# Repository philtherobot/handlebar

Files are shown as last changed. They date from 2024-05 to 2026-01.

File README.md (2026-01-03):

### Ergogen

Online design tool at https://ergogen.cache.works/.

Elite-C https://deskthority.net/wiki/Elite-C footprint from ceoloide: https://github.com/ceoloide/ergogen-footprints

Running ergogen:

```
cd handlebar
ergogen . -o output
```

Pass a folder instead of an input file name because handlebar has custom footprints and that's how this works.

### Parts

- Choc v1 switches (Keebd)
- DMK keycaps, 1U (Keebd)
- Elite-C v4, 2 parts (Omega Keys)
- TRRS PJ-320A jack, 2 parts (Clickety Split)
- TRRS cable (Clickety Split)
- Diodes 1N4148W, SOD-123, 50 parts (Digikey 4530-1N4148WCT-ND)
- Push buttons FSMCTTR, 2 parts (Digikey 450-2133-1-ND)
- RGB LEDs FZ2812-5050, QMK compatible (WS2812B) (Digikey, 4544-FZ2812-5050CT-ND)
- MCU socket 801-43-064-10-002000 (Digikey, ED10864-64-ND)
- PCBs, 2 parts
- USB-C/USB cable

The Atmega32u4 on the Elite-C has 32KB flash, 2.5KB SRAM, 16MHz CPU.

#### Base

Mild steel plate, 1/16", 5/64" or 3/32" thick. 1.5mm to 2.5mm thick. 200x150mm or 8"x6", two times.

We plan to either solder the standoff or screw them.

- 8mm long, M2 standoff, 6 times
- dome head M2 screws, 6mm of thread, 6 times
- dome head M2 screws, 4mm of thread, 8 times
- flat head M2 screws, 6mm full length, 6 times
- flat head M2 screws, 10mm full length, 8 times
- M2 nuts, 8 times

### Cost

Elite-C at Omega Keys, 24$ each.
Keycaps and switches, 114$
PCB, JLCPcb, 
TRRS cable
Digi-key

#### Not used, extra
Switches, 13$
TRRS cable, Keebd, 7$ (not used)

### KiCAD 

Tutorial: https://flatfootfox.com/ergogen-part5-kicad-firmware-assembly/

We are better to use constraints from makers. JLCPCB seems to have less capability than others. I found a Kicad board with JLC's capability set. See `JLCPCB_1-2Layer template`.

*DO NOT* edit the elite-c footprint as this will introduce a lot of errors! The errors are introduced because the nets that were setup by Ergogen are lost during the footprint edition.

Steps after ergogen has been executed:
- Import board settings from JLCPCB_1-2Layer template:
  - File/Board Setup/Import from another board. 
  - Turn User.Drawings back on.
  - Change track width to 0.25mm in Net Classes
- add the resistors footprints, R_Axial_DIN0207_L6.3mm_D2.5mm_P10.16mm_Horizontal
  - under the TRRS
  - do not show the reference
- change footprint of indicators to Personal:WS2812B
- (useful: Route/Interactive Router Setting, try Highlight + Free angle or Walk around)
- complete the net connections for the resistors on front of board (VCC on the right, SDA at the top, SCL at the bottom)
- add a via below the indicators for VCC
- wire keys pin 1 (2 of them) to diode 2 on the back
- wire diode pads to holes on the front and back
- wire columns on the back
- route columns around the top and through the middle of the MCU, starting with n_inner
- wire rows on the front: they enter the MCU from the left
- wire reset, place it on the right
- wire VCC on the left of reset *and* go from the second resistor to the via on the *back*
- wire ground, going between n_vcc and n_scl on the TRRS connector, up on the left of VCC
- wire ground to all ground pins on the MCU
- wire SDA from TRRS to the MCU on the back
- indicator grounds
- indicator "next" and to the MCU

Optional:
- give a little bit of space around pads and traces
- add the name and version on the silkscreens

### Fabrication

Prepare Gerber files:
- File/Fabrication/Gerbers
- Check the layers
  - *.Cu, *.Paste, *.Mask, *.Silkscreen, Edge.Cuts
- Set a clean, new, empty directory
- Plot
- Generate drill files
- Zip the output files, flat, no directory

Upload to JLCPCB (https://jlcpcb.com/)

PCB material is FR-4. Use the defaults (1.6mm). Remove JLC's serial numper. Pick your color. 

### Notes

Elite-C information:
- https://deskthority.net/wiki/Elite-C
- Development history, reveals a lot about how it works: https://blog.keeb.io/case-of-the-wayward-elite-c/
- Atmega34U4, Atme AVR

https://flatfootfox.com/ergogen-part3-pcbs/

This has example of adding a PCB via: https://github.com/ergogen/ergogen/blob/675d2709dc4c2515ec34ecf4e5148127495283f3/config.yaml

PCM12 is a sliding switch. (no need it seems)

b3u1000p is a small reset push button. https://www.allaboutcircuits.com/electronic-components/datasheet/B3U-1000P-B--Omron/

This looks close to what I am trying to do: https://github.com/davidphilipbarr/Sweep/tree/main/Sweep%20half-swept

Redox schematic https://github.com/mattdibi/redox-keyboard/blob/master/redox/pcb/Redox-schematic.pdf

# Hardware Checklist

- [x] MCU position on the PCB matches the one in the preview.
- [x] Through holes are the correct size for my components.
- [x] Fit between the diode and the switch.
- [x] Pull up 4.7KΩ resistors, SDA to VCC, SCL to VCC
- [x] Must I²C be connected to those two specific pins? D0 and D1? Yes, let's do that.
- [x] Should I ground all unused pins? No. And there is no need to cover the unused space with ground copper.
- [x] Are the back diodes pads connected to the traces on front? No and I added them.
- [x] Decide on PCB thickness: 1.6mm
- [x] What is the voltage needed by the RGB LEDs? 3V, so VCC is good. Crossed fingers.

# Key Layout

Diagrams are made with [Keyboard Layout Editor](https://www.keyboard-layout-editor.com/).

I have linked the Keyboard Layout Editor account with my Github account. In any case, I saved the diagrams to `key_layout`.

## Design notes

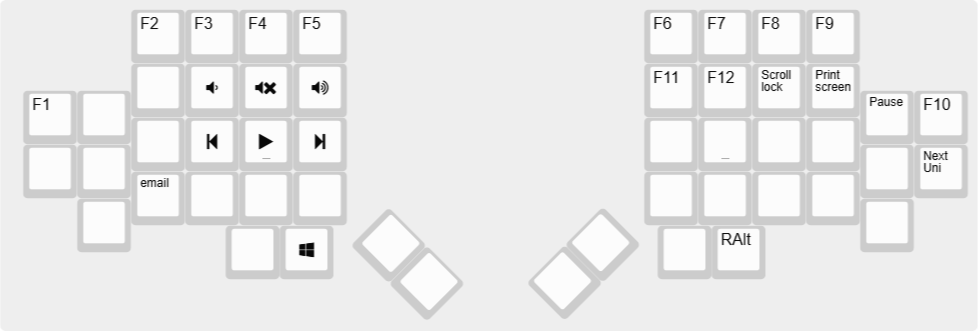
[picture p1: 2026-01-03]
key_layout/jan2026/handlebar-functions.png

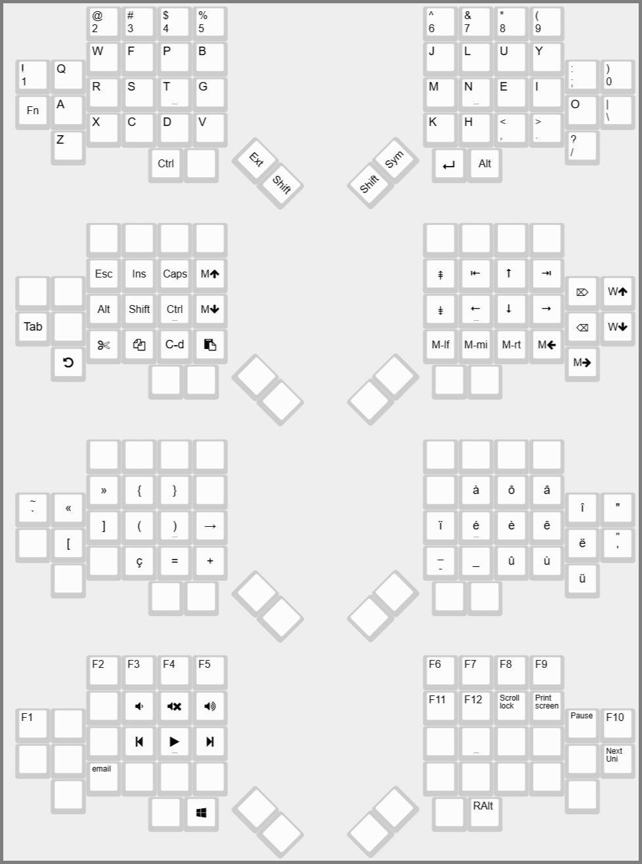
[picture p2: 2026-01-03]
key_layout/jan2026/handlebar-layout.png

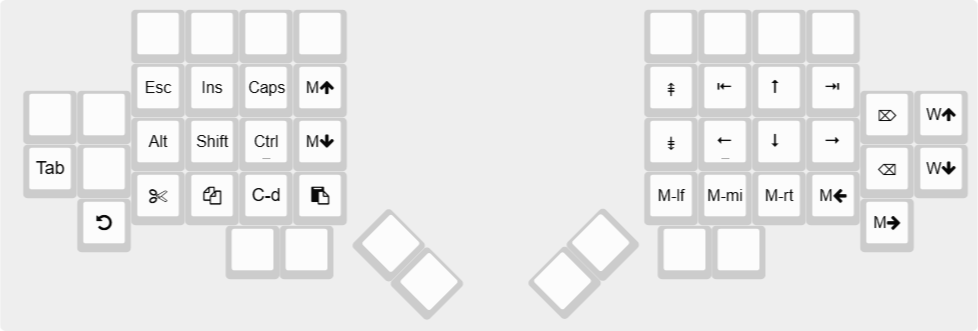
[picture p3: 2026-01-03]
key_layout/jan2026/handlebar-extend.png

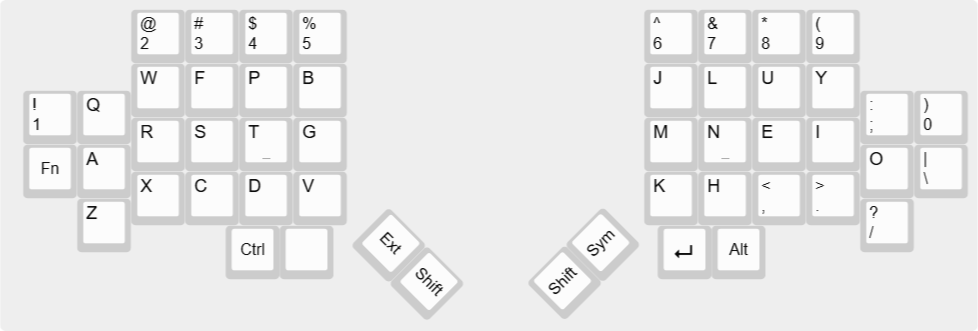
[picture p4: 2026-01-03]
key_layout/jan2026/handlebar-base-layer.png

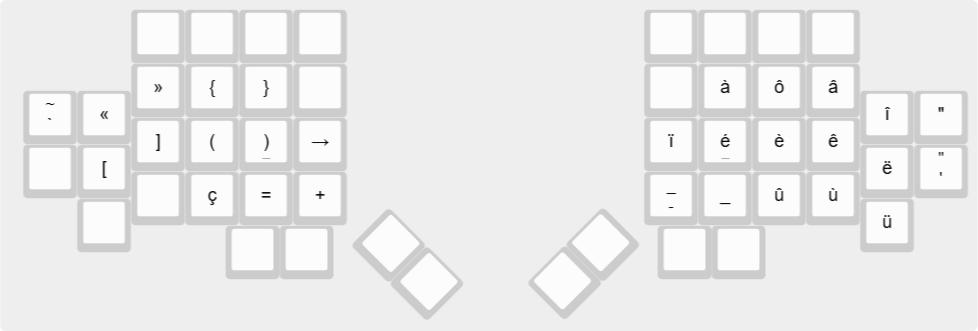
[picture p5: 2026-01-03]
key_layout/jan2026/handlebar-symbols.png

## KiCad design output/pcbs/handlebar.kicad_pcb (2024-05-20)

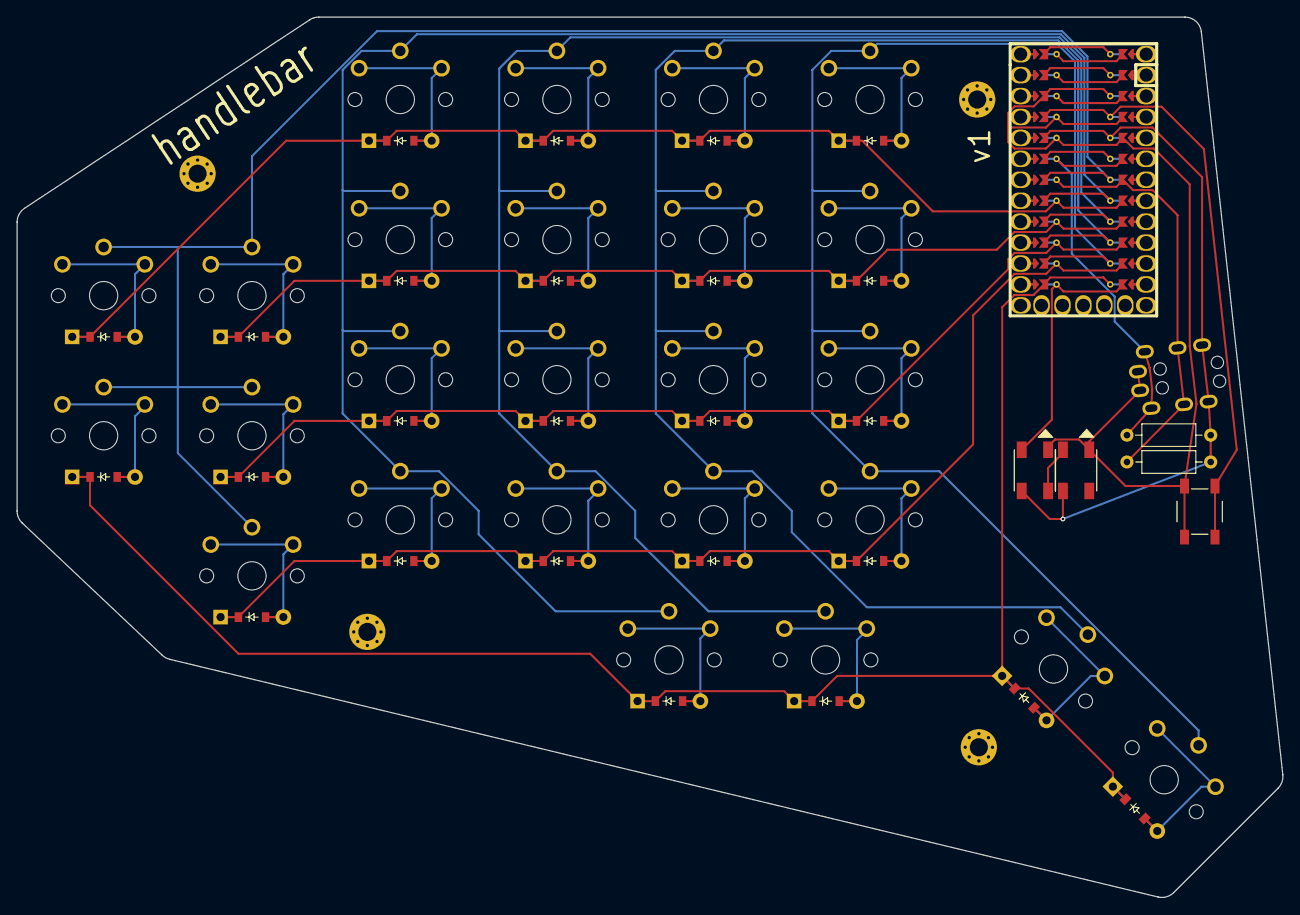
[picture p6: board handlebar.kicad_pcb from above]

Board: 4 copper layers, 153.6 x 106.8 mm, 58 parts (0 on the bottom side), 38 nets.

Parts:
D1, D2, D3, D4, D5, D6, D7, D8, D9, D10, D11, D12, D13, D14, D15, D16, D17, D18, D19, D20, D21, D22, D23, D24, D25: ComboDiode
I1, I2: WS2812B
S1, S2, S3, S4, S5, S6, S7, S8, S9, S10, S11, S12, S13, S14, S15, S16, S17, S18, S19, S20, S21, S22, S23, S24, S25: PG1350
TRRS1: TRRS-PJ-320A-dual
_2, _3, _4, _5: MountingHole_2.2mm_M2_Pad_Via
rst1: SW_TACT_ALPS_SKQGABE010

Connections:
center_thumb: D24.2, S24.1
index_bottom: D9.2, S9.1
index_home: D10.2, S10.1
index_nums: D12.2, S12.1
index_top: D11.2, S11.1
inner_bottom: D13.2, S13.1
inner_home: D14.2, S14.1
inner_nums: D16.2, S16.1
inner_thumb: D25.2, S25.1
inner_top: D15.2, S15.1
left_thumb: D22.2, S22.1
middle_bottom: D5.2, S5.1
middle_home: D6.2, S6.1
middle_nums: D8.2, S8.1
middle_top: D7.2, S7.1
n_bottom: D1.1, D5.1, D9.1, D13.1, D19.1
n_gnd: I1.33, I2.33, TRRS1.1, rst1.2
n_home: D2.1, D6.1, D10.1, D14.1, D20.1
n_index: S9.2, S10.2, S11.2, S12.2, S24.2
n_indic_next: I1.22, I2.44
n_inner: S13.2, S14.2, S15.2, S16.2, S25.2
n_middle: S5.2, S6.2, S7.2, S8.2, S23.2
n_nums: D4.1, D8.1, D12.1, D16.1, D18.1
n_pinky: S17.2, S18.2, S19.2, S20.2, S21.2
n_ring: S1.2, S2.2, S3.2, S4.2, S22.2
n_thumb: D17.1, D22.1, D23.1, D24.1, D25.1
n_top: D3.1, D7.1, D11.1, D15.1, D21.1
n_vcc: I1.11, I2.11, TRRS1.4
outer_home: D17.2, S17.1
outer_top: D18.2, S18.1
pinky_bottom: D19.2, S19.1
pinky_home: D20.2, S20.1
pinky_top: D21.2, S21.1
right_thumb: D23.2, S23.1
ring_bottom: D1.2, S1.1
ring_home: D2.2, S2.1
ring_nums: D4.2, S4.1
ring_top: D3.2, S3.1

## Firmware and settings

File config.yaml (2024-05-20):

meta:
  version: 1
  author: philtherobot
  engine: 4.0.2
units:
  # cx, cy = Choc V1 spacing, 18×17
  # physical DMK keycap size = 17.5×16.5
  # We want a familiar horizontal spacing.
  # So spread = 19 (standard = u).
  # We want tighter as possible vertically
  # because we have four rows.
  # So padding = 17 (cy)

  spread: u     # 19mm
  padding: cy   # 17mm
  kcapx: 17.5
  kcapy: 16.5

  # Shifts around points to stretch the "board" polygon
  bpadx: cx / 2 + 1.5 
  bpady: cy / 2 + 1.5

  mcuwidth: 17.78
  mcuheight: 33.02
  mcushiftx: 0.5cx + mcuwidth/2 + 8
  mcushifty: 0.5cy - mcuheight/2 - 3

  resetwidth: 5
  resetheight: 5
  resetshiftx: 40
  resetshifty: -50

  trrswidth: 6
  trrsheight: 14
  trrsshiftx: 44
  trrsshifty: -34
  trrsrotate: -83.4

  indicatorwidth: 5
  indicatorheight: 5
  indicatorshiftx: 20
  indicatorshifty: -45

points:
  key:
    spread: spread
    padding: padding

  zones:
    # The central 4×4 matrix
    center:
      # Fix placement on KiCAD sheet.
      anchor:
        shift: [100, -100]

      columns:
        ring:
          key:
            col_net: n_ring
        middle:
          key:
            col_net: n_middle
        index:
          key:
            col_net: n_index
        inner:
          key:
            col_net: n_inner

      rows:
        bottom:
          row_net: n_bottom
        home:
          row_net: n_home
        top:
          row_net: n_top
        nums:
          row_net: n_nums

    # The keys at the outer edge
    wing:
      key:
        spread: cx  # Tighter spread for the pinky
        col_net: n_pinky # All those keys are in a single net column

      anchor:
        ref: center_ring_bottom
        shift: [-2cx, -0.4cy]

      columns:
        outer:
          rows:
            bottom.skip: true
            home.row_net: n_thumb
            top.row_net: n_nums
        pinky:

      rows:
        bottom:
          row_net: n_bottom
        home:
          row_net: n_home
        top:
          row_net: n_top

    # The lower keys for the thumb
    thumb:
      anchor:
        ref: center_index_bottom
        shift: [-0.3cx, -padding]
      columns:
        left:
           key:
             col_net: n_ring
        right:
          key:
            col_net: n_middle
        center:
          key:
            splay: -45
            origin: [3, -11]
            col_net: n_index
        inner:
          key:
            col_net: n_inner
      rows:
        thumb:
          row_net: n_thumb

outlines:
  # "keycaps" is the positions of the DMK keycaps
  keycaps:
    - what: rectangle
      where: true
      size: [kcapx, kcapy]

  raw:
    - what: rectangle
      where: true
      size: [cx+1, cy+1]

  board:
    - what: polygon
      fillet: 2
      points:
        - ref: wing_outer_home
          shift: [-bpadx, -bpady]
        - ref: wing_outer_top
          shift: [-bpadx, bpady]
        - ref: center_ring_nums
          shift: [-bpadx, bpady]
        - ref: center_inner_nums
          shift: [bpadx, bpady]
        - ref: center_inner_nums
          shift: [40, bpady]
        - ref: thumb_inner_thumb
          shift: [bpadx, bpady]
        - ref: thumb_inner_thumb
          shift: [bpadx, -bpady]
        - ref: wing_pinky_bottom
          shift: [-bpadx, -bpady]

  mcu:
    - what: rectangle
      size: [mcuwidth, mcuheight]
      adjust: 
        ref: center_inner_nums
        shift: [mcushiftx, mcushifty] 

  reset:
    - what: rectangle
      size: [resetwidth, resetheight]      
      adjust:
        ref: center_inner_nums
        shift: [resetshiftx, resetshifty]

  trrs:
    - what: rectangle
      size: [trrswidth, trrsheight]
      adjust: 
        ref: center_inner_nums
        shift: [trrsshiftx - 5, trrsshifty - 1]
        rotate: trrsrotate

  indicator1:
    - what: rectangle
      size: [indicatorwidth, indicatorheight]
      adjust:
        ref: center_inner_nums
        shift: [indicatorshiftx, indicatorshifty]

  indicator2:
    - what: rectangle
      size: [indicatorwidth, indicatorheight]
      adjust:
        ref: center_inner_nums
        shift: [indicatorshiftx + indicatorwidth, indicatorshifty]

  preview:
    - name: board
    - operation: stack
      name: keycaps
    - operation: stack
      name: mcu 
    - operation: stack
      name: reset
    - operation: stack
      name: trrs  
    - operation: stack
      name: indicator1
    - operation: stack
      name: indicator2
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

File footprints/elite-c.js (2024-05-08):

/*

Author: @Virginia2244

Description:
  A reversable footprint for the elite-c microcontroller.

Datasheet: (really just a wiki but it was the closest I could find)
  https://deskthority.net/wiki/Elite-C

Params
  reversable: default is false
    When enabled the PCB is reversable
  label: default is true
    Turns on and off the elite-c label
  instructions: default is true
    turns on and off the instructions about which side to solder the
  jumpers traces: default is true
    Turns on and off auto tracing for the reversable pins
  reversable_pins: default is 5
    How many pins need to be reversable? Only the top 5 need to
    be reversable because they aren't GPIO. After that the pins are changable in
    the firmware.
*/


module.exports = {
  params : {
    reversable : {type : 'boolean', value : false},
    label : {type : 'boolean', value : true},
    instructions : {type : 'boolean', value : true},
    traces : {type : 'boolean', value : true},
    reversable_pins : {type : 'boolean', value : 5},

    D3 : {type : 'net', value : 'D3'},
    D2 : {type : 'net', value : 'D2'},
    D1 : {type : 'net', value : 'D1'},
    D0 : {type : 'net', value : 'D0'},
    D4 : {type : 'net', value : 'D4'},
    C6 : {type : 'net', value : 'C6'},
    D7 : {type : 'net', value : 'D7'},
    E6 : {type : 'net', value : 'E6'},
    B4 : {type : 'net', value : 'B4'},
    B5 : {type : 'net', value : 'B5'},

    B0 : {type : 'net', value : 'B0'},
    F4 : {type : 'net', value : 'F4'},
    F5 : {type : 'net', value : 'F5'},
    F6 : {type : 'net', value : 'F6'},
    F7 : {type : 'net', value : 'F7'},
    B1 : {type : 'net', value : 'B1'},
    B3 : {type : 'net', value : 'B3'},
    B2 : {type : 'net', value : 'B2'},
    B6 : {type : 'net', value : 'B6'},

    VBUS : {type : 'net', value : 'VBUS'},
    GND : {type : 'net', value : 'GND'},
    RST : {type : 'net', value : 'RST'},
    VCC : {type : 'net', value : 'VCC'},

    B7 : {type : 'net', value : 'B7'},
    D5 : {type : 'net', value : 'D5'},
    C7 : {type : 'net', value : 'C7'},
    F1 : {type : 'net', value : 'F1'},
    F0 : {type : 'net', value : 'F0'},

  },
  body : p => {
      /* Putting the nets into an array so that it can be itterated through */
      const pin_nets = [
        [`${p.VBUS.str}`, `${p.VBUS.str}`],
        [`${p.D3.str}`,   `${p.B0.str}`],
        [`${p.D2.str}`,   `${p.GND.str}`],
        [`${p.GND.str}`,  `${p.RST.str}`],
        [`${p.GND.str}`,  `${p.VCC.str}`],
        [`${p.D1.str}`,   `${p.F4.str}`],
        [`${p.D0.str}`,   `${p.F5.str}`],
        [`${p.D4.str}`,   `${p.F6.str}`],
        [`${p.C6.str}`,   `${p.F7.str}`],
        [`${p.D7.str}`,   `${p.B1.str}`],
        [`${p.E6.str}`,   `${p.B3.str}`],
        [`${p.B4.str}`,   `${p.B2.str}`],
        [`${p.B5.str}`,   `${p.B6.str}`],
      ]

      /*These constants are the magic of this code, they allow us to adjust almost everything important aspect of the microcontroller.
      The reason this is helpfull is that if you don't want to use a Seeed Xiao you can easily adjust the paramiters to make a different microcontroller.
      
      top_left_pin: This is the position of the top left pin of the microcontroller.
      top_right_pin: This is the position of the top right pin of the microcontroller.
      pin_dist: The distance in between each pin horizontaly
      total_pin_num: The total number of pins the microcontroller has. This number must be divisable by two.
      pin_to_male_pad: The distance from the pin on the microcontroller to the male pad.
      pin_to_female_pad: The distance from the pin on te microcontroller to the female pad.
      pin_to_via: the distance from the pin on the microcontroller to the via.
      */
      const spacing = {
        top_left_pin:  {x: -7.62, y: -16.51},
        top_right_pin: {x:  7.62, y: -16.51}, 
        pin_dist: 2.54,
        total_pin_num: 26, //Must be an even number
        pin_to_male_pad: 2,
        pin_to_female_pad: 2.845,
        pin_to_via: 4.358,
      }

      /*The other distances needed to make the traces work. This is basically just two points. 
      
      top_left      top_right
        ^              ^
        /``````````````\
       [] 0             O []
           \............../
            ^             ^
      bottom_left   bottom_right

      The number is the distance from the pin to the corner of the trace. */
      const trace_spacing = {
        top_left:     {x: 3.6, y: .85},
        top_right:    {x: 5.2, y: .85},
        bottom_left:  {x: 5.2, y: .85},
        bottom_right: {x: 3.6, y: .85},
      }

      /*Generates the through holes on sides of the microcontroller*/
      const get_thru_hole = () => {
        let thru_hole = ''
        /* Starts at the top two microcontrollers and goes down. 
        It makes the nets of each pin internal if it suposed to be a reversable pin otherwise it takes from the pin_nets values.*/
        for (let i = 0; i < spacing.total_pin_num/2; i++) {
          // Only place a pin hole for the top VCC if it reversavle
          if(i == 0){
            thru_hole += p.reversable ? `(pad ${i} thru_hole oval (at ${spacing.top_left_pin.x}  ${spacing.top_left_pin.y + (i)*spacing.pin_dist}  ${p.rot})       (size 2.5 2) (drill 1.6) (layers *.Cu *.Mask) 
            ${pin_nets[i][0]})\n` : ``
          
            thru_hole +=`(pad ${spacing.total_pin_num - 1 - i} thru_hole oval (at ${spacing.top_right_pin.x} ${spacing.top_right_pin.y + (i)*spacing.pin_dist} ${180 + p.rot}) (size 2.5 2) (drill 1.6) (layers *.Cu *.Mask) ${pin_nets[i][1]})\n`
            continue;
          }
          thru_hole += `(pad ${i}                             thru_hole oval (at ${spacing.top_left_pin.x}  ${spacing.top_left_pin.y + (i)*spacing.pin_dist}  ${p.rot})       (size 2.5 2) (drill 1.6) (layers *.Cu *.Mask) ${p.reversable && (i < p.reversable_pins) ? p.local_net(i).str : pin_nets[i][0]})\n`
          
          thru_hole += `(pad ${spacing.total_pin_num - 1 - i} thru_hole oval (at ${spacing.top_right_pin.x} ${spacing.top_right_pin.y + (i)*spacing.pin_dist} ${180 + p.rot}) (size 2.5 2) (drill 1.6) (layers *.Cu *.Mask) ${p.reversable && (i < p.reversable_pins) ? p.local_net(spacing.total_pin_num - 1 - i).str : pin_nets[i][1]})\n`
        }
        return thru_hole
      }

      /* Adds the bottom row of pins */
      const through_hole_bottom = `
      (pad 30  thru_hole oval  (at -5.08 13.97) (size 2 2.5) (drill 1.6) (layers *.Cu *.Mask) ${p.B7.str})
      (pad 29  thru_hole oval  (at -2.54 13.97) (size 2 2.5) (drill 1.6) (layers *.Cu *.Mask) ${p.D5.str})
      (pad 28  thru_hole oval  (at  0    13.97) (size 2 2.5) (drill 1.6) (layers *.Cu *.Mask) ${p.C7.str})
      (pad 27  thru_hole oval  (at  2.54 13.97) (size 2 2.5) (drill 1.6) (layers *.Cu *.Mask) ${p.F1.str})
      (pad 26  thru_hole oval  (at  5.08 13.97) (size 2 2.5) (drill 1.6) (layers *.Cu *.Mask) ${p.F0.str})
`
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

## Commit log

2024-03-25 update kicad files
    [handlebar.kicad_pcb]
2024-04-24 Added doc, remove non-source folders, added gitignore
    [board.dxf, board_and_keycaps.dxf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]
2024-04-24 Added Kicad project
    [handlebar.kicad_pcb, handlebar.kicad_sch]
2024-04-25 Nets have started working, diodes
    [handlebar.kicad_pcb]
2024-05-02 Board description is now decidely moving towards production. Changed Elite-C footprint for a better one. Clone the diode footprint and removed the through holes. Cloned the Choc footprint in preparat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
    [handlebar.kicad_pcb]
2024-05-02 Through hole 2 only added once for the Choc footprint
2024-05-02 Added the reset button, TRRS and two indicator RGB LEDs.
    [handlebar.kicad_pcb]
2024-05-03 Adjust TRRS position
    [handlebar.kicad_pcb]
2024-05-03 Add mounting holes
    [handlebar.kicad_pcb]
2024-05-07 Board description is now decidely moving towards production. Changed Elite-C footprint for a better one. Clone the diode footprint and removed the through holes. Cloned the Choc footprint in preparat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
    [handlebar.kicad_pcb]
2024-05-08 Added vias to the diodes. Changed holes for the MCU. Made space for the resistors. Inverted the switches pins to diodes. Rotated the indicators.
    [handlebar.kicad_pcb]
2024-05-09 Removed/replaced the "outer" column. Reoriented the indicators. Rearranged the pin assignments. More instructions post-Ergogen.
    [handlebar.kicad_pcb]
2024-05-10 Went back to using regular diodes. Kicad JLC template. Updated instructions. Rotated RST.
    [JLCPCB.kicad_pcb, JLCPCB.sch]
2024-05-10 Updated gitignore and removed non-source file. This is now the first "I feel like I can produce this" board.
2024-05-10 Updated gitignore
    [handlebar.kicad_pcb]
2024-05-10 Changed the big name. Better parts list.
    [handlebar.kicad_pcb]
2024-05-20 v1 complete and sent to maker
    [handlebar.kicad_pcb]
2024-05-20 Commit the Gerber zip file and the correct footprint library
